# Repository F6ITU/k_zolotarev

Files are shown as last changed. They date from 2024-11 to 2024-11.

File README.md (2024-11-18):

# Zolotarev Low Pass Filter

This lpf filter has been described by Gary Cobb, G3TMG, in QEX (November-December 2016). 

Based on this model, Kjell LA2NI designed a complete low-pass filter, capable of handling (at least) 600W of RF power. 

It's the ideal companion for the Munin400 linear amplifier designed by the same author.

This repository is a strict copy of the original work, using Kicad 8.xx. Original pcb design was made with Ultiboard software

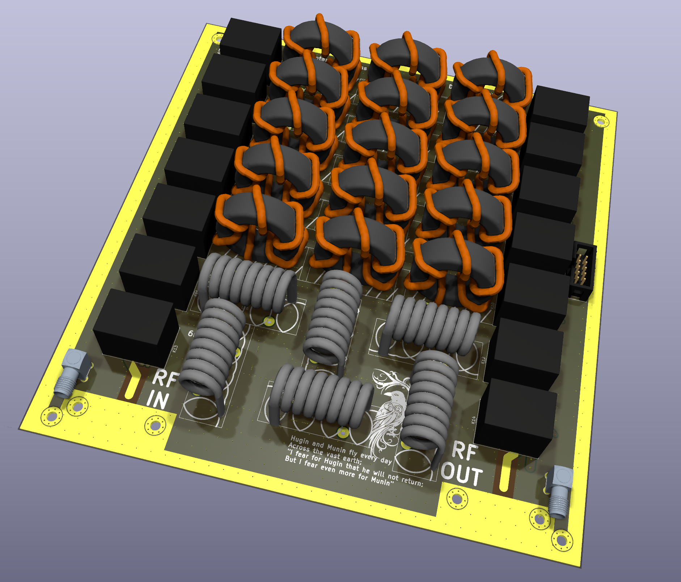
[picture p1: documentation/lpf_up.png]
LPF vu de dessus


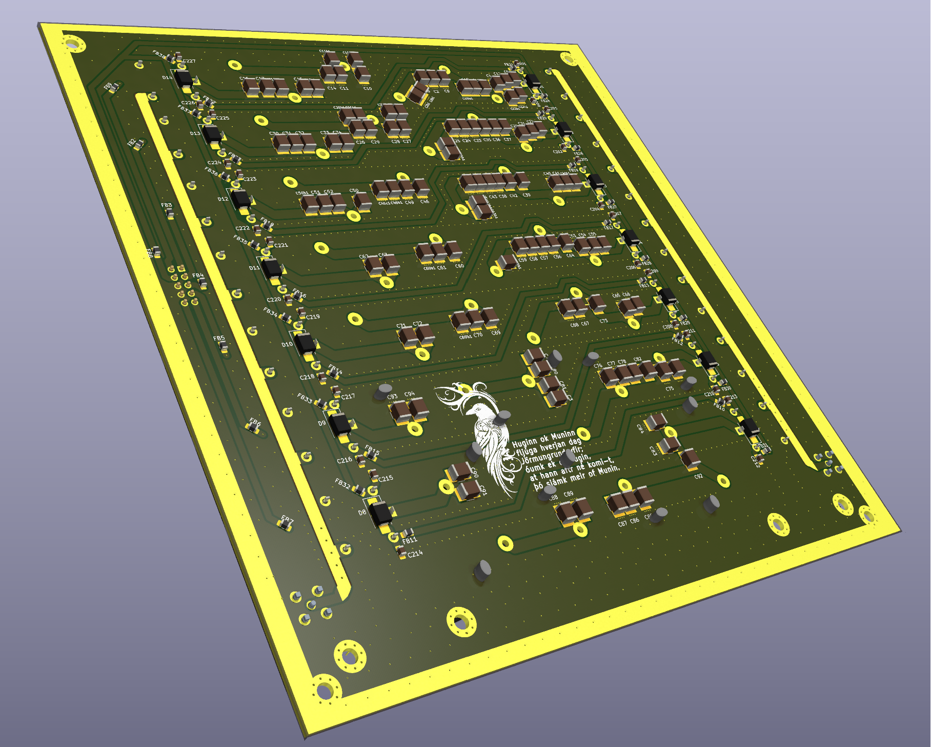
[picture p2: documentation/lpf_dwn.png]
LPF vu de dessous


# Building notes : 

** All capacitors used in the active part of the filter have been sourced as "Vishay Vitramon VJ Hifreq" in 1111 format./**

For   safety reasons and voltage/power handling, the operating voltage of each capacitor should not be less than 1kV.

In other words, since the voltage withstand of MLCC capacitors (or any other technology) decreases as the capacitance increases, the maximum value of each component must not exceed 180 pF (beyond this value, the voltage withstand
resistance collapses at 630 V).

This is why parallel capacitor associations have been provided on the pcb (referenced with the suffix Cxxb1, Cxxb2 etc).

** Two kind of output are available.

- One on SMA connectors

- The other by soldering a coaxial cable directly to the pcb (pigtail input/output)

The second method is preferable, as it's more practical for many hobbyists. However, at these frequencies (1 to 60 MHz), SMA connectors support these power levels perfectly. Avoid connectors made in China.

Input and output wiring on 5mm coax such as RG233 or equivalent (or hand formable SM141 coax cable if SMA are used).

Toroid should be wound with 6 to 8 tenths of a mm wire, air-cores with 8/10 silver-plated wire.

# Work in progress ?

The current state of the filter is considered as "RTM", Beta 1, and considered as "almost definitive" for a first version.

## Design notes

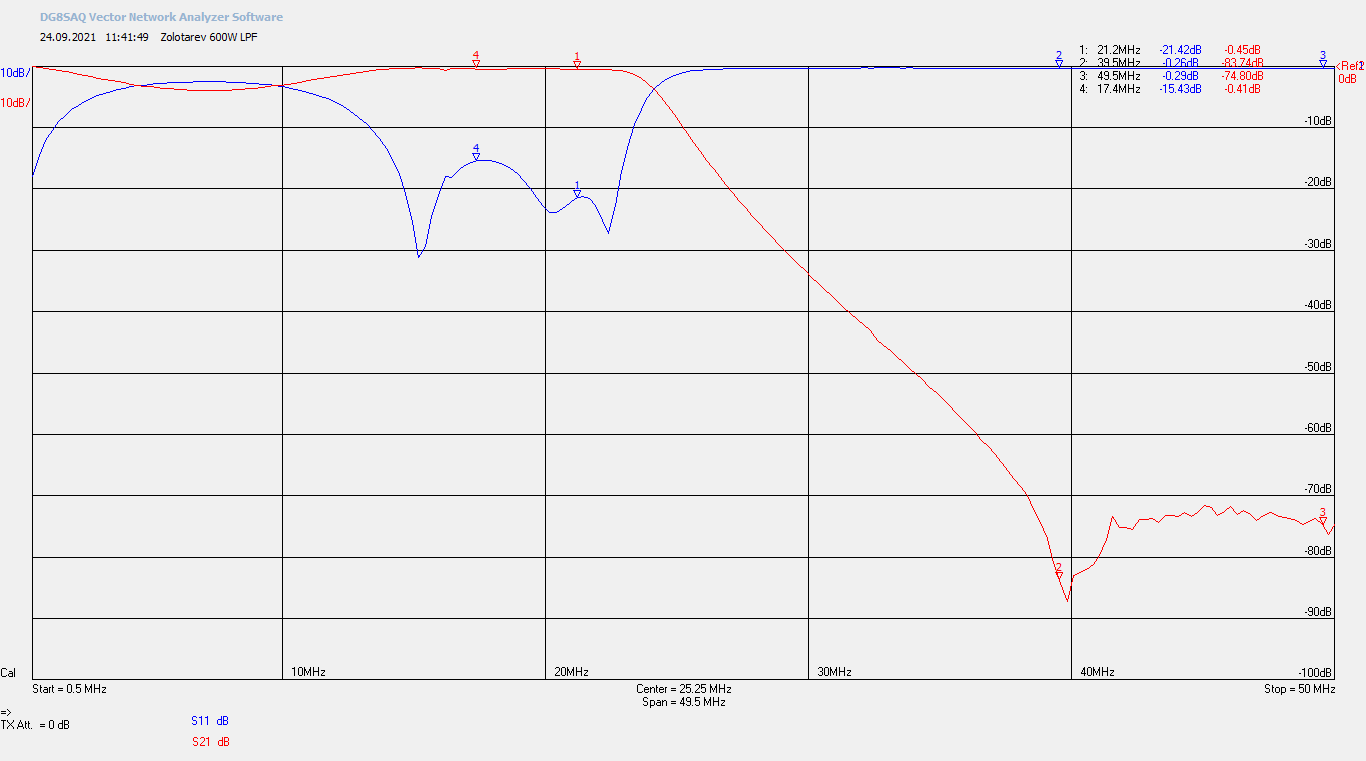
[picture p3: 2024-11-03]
documentation/original LA2NI files/Zolotarev 600W LPF_18+15 metre.png

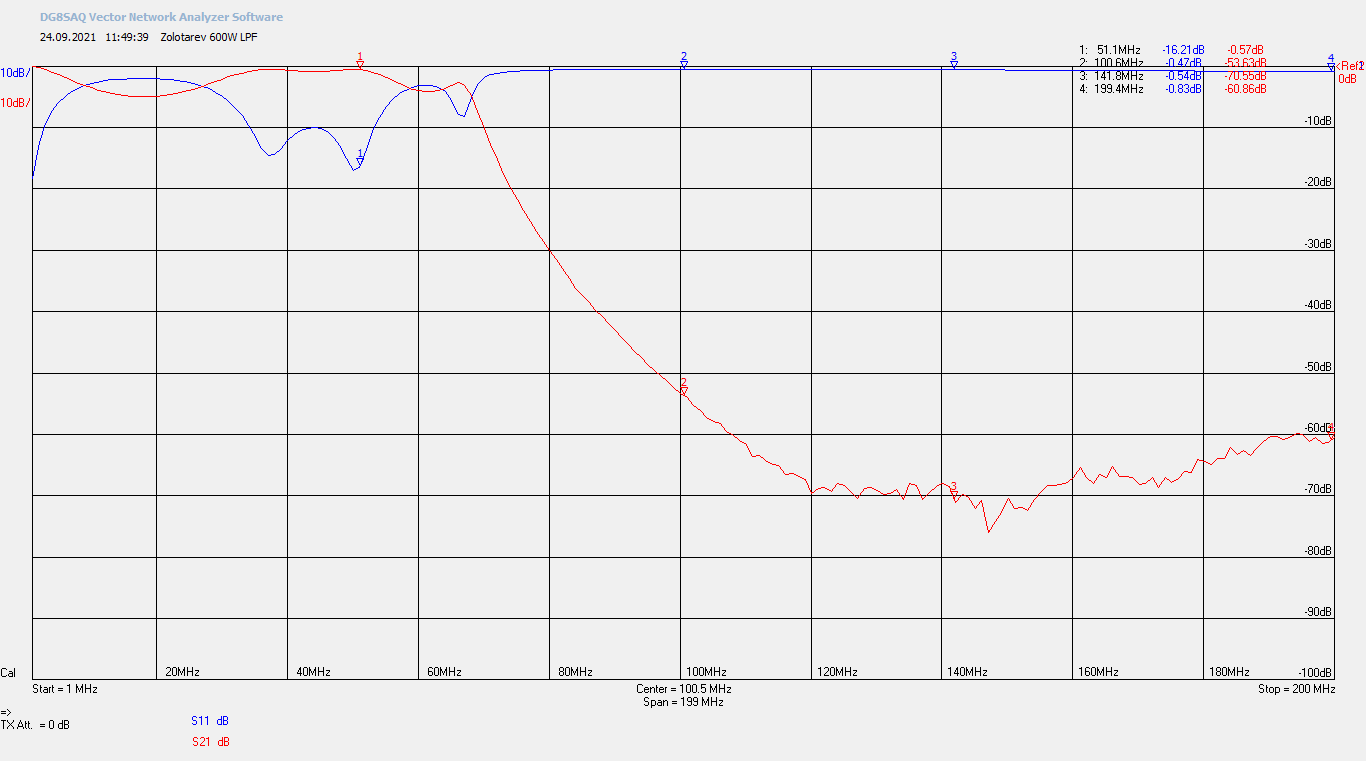
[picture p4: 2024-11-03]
documentation/original LA2NI files/Zolotarev 600W LPF_6 metre.png

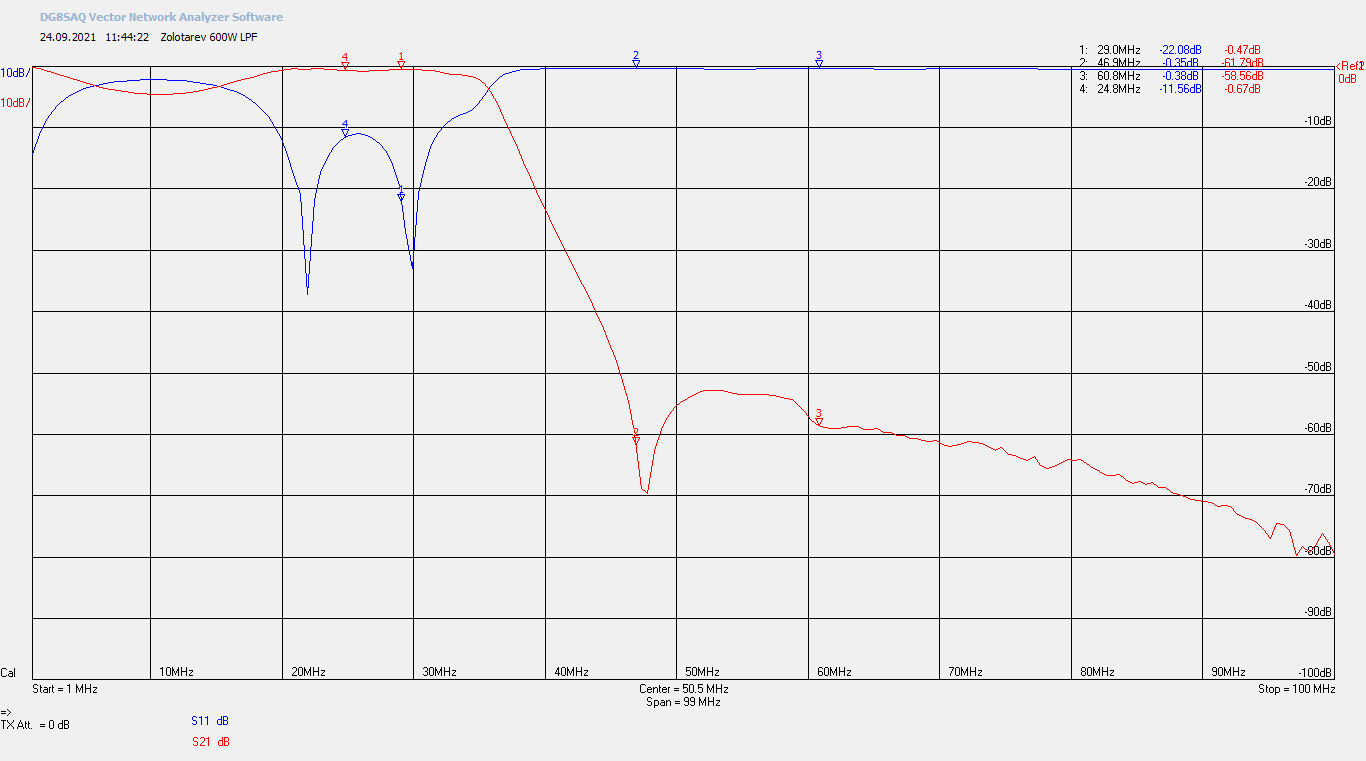
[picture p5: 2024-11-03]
documentation/original LA2NI files/Zolotarev 600W LPF_12+10 metre.png

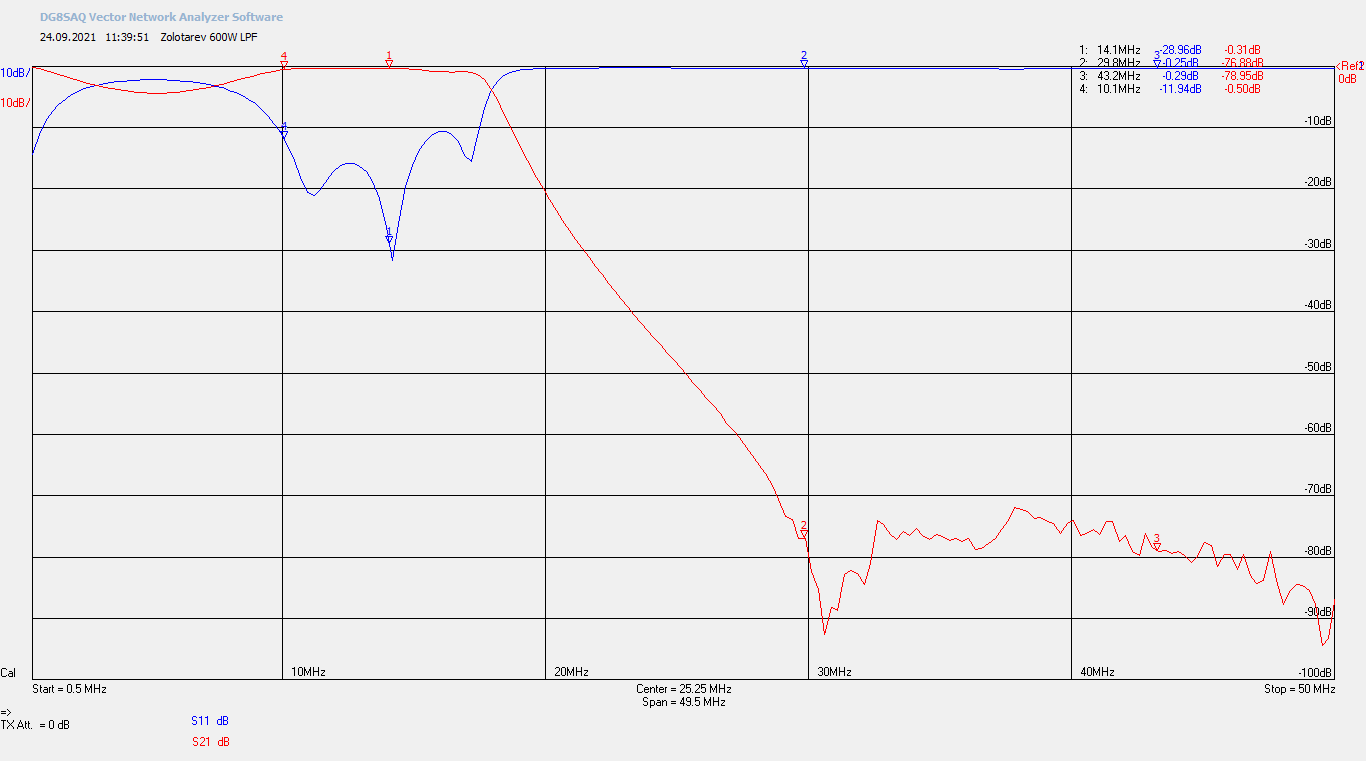
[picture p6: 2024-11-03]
documentation/original LA2NI files/Zolotarev 600W LPF_30+20 metre.png

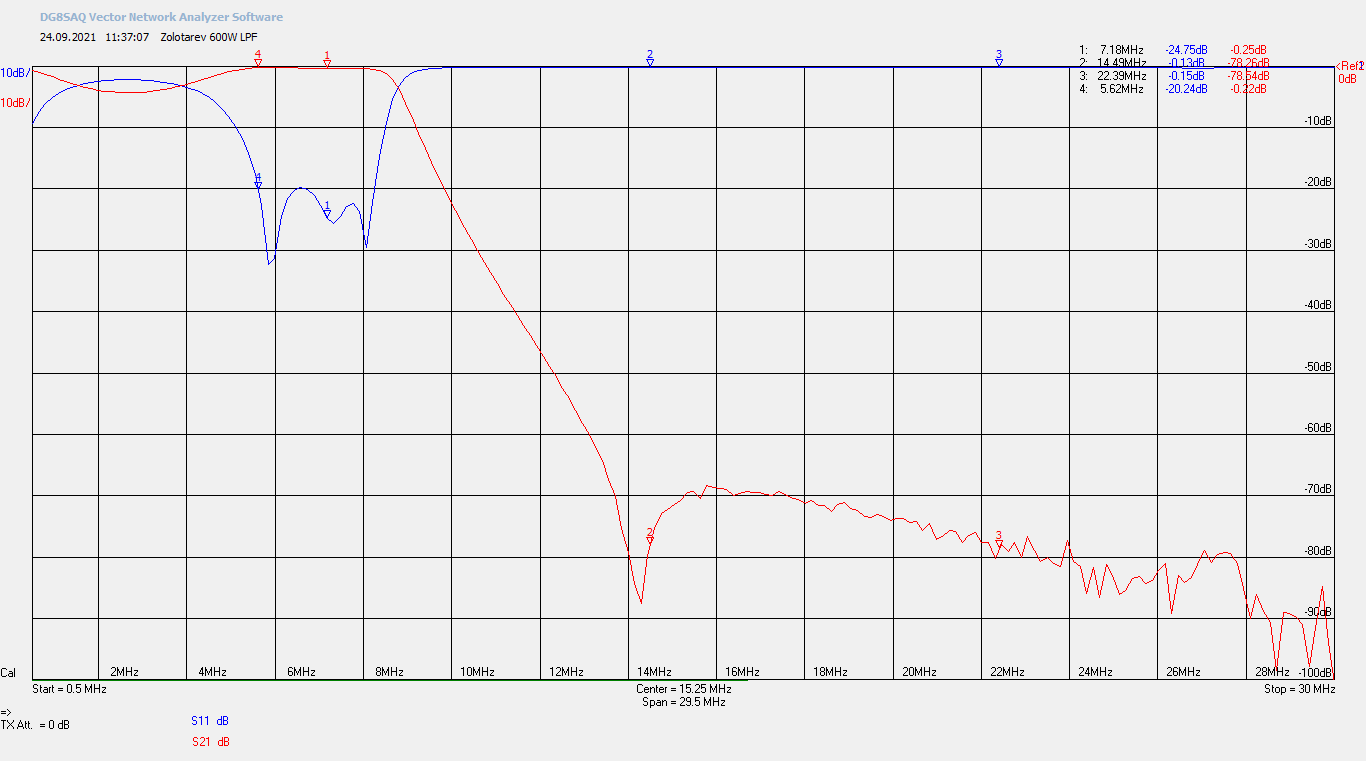
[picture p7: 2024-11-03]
documentation/original LA2NI files/Zolotarev 600W LPF_60+40 metre.png

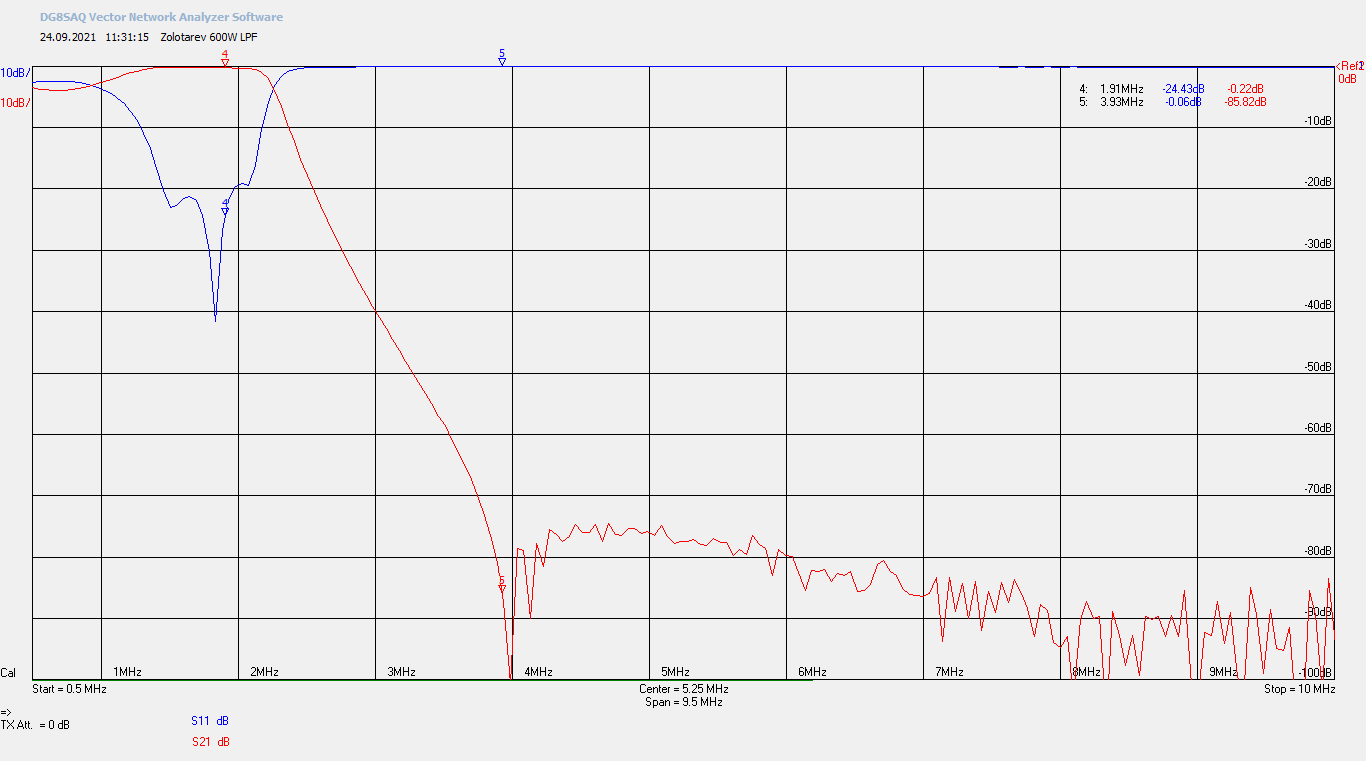
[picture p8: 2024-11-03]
documentation/original LA2NI files/Zolotarev 600W LPF_160 metre.png

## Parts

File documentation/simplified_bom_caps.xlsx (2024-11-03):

valeur | qté | ref mouser | P.U. | total
6
7
10 | X2
11
12 | X2
13
20 | X3
22 | X2
25
29 | X2
30 | X2
33
38
40 | X2
52
68 | X7
100
120
130 | X14
180 | X5
200 | X12
620 | X5
680 | x3
1000 | x7
2200 | x2
2700 | x4
5600
6200

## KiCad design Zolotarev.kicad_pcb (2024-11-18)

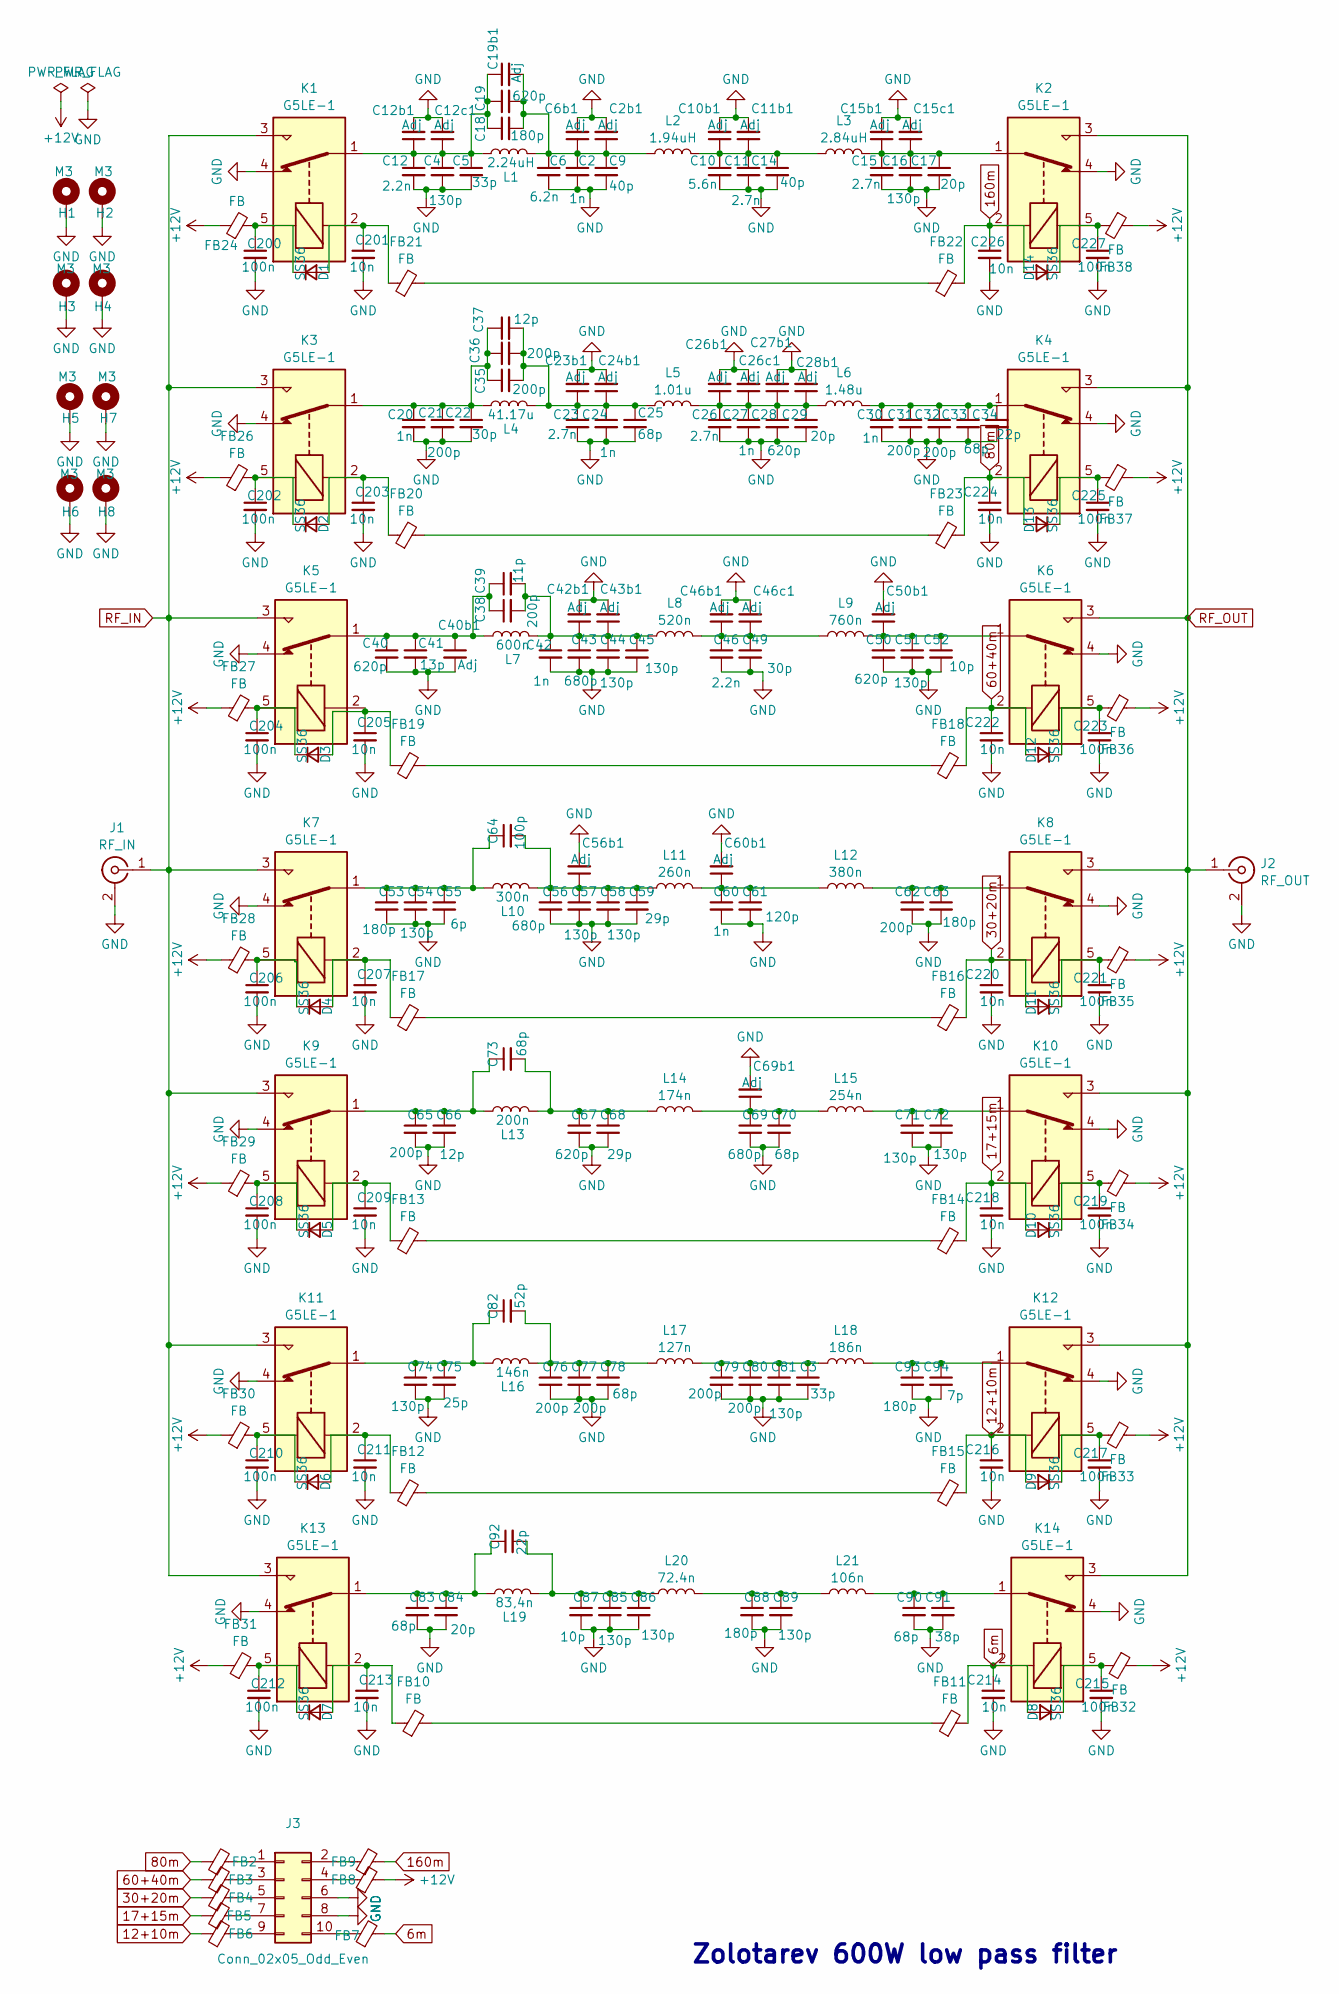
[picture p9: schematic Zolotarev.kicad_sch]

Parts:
C2, C20, C24, C27, C30, C42, C60: 1n; ATC_500_HandSoldering
C2b1, C6b1, C10b1, C11b1, C12b1, C12c1, C15b1, C15c1, C19b1, C23b1, C24b1, C26b1, C26c1, C27b1, C28b1, C40b1, C42b1, C43b1, C46b1, C46c1, C50b1, C56b1, C60b1, C69b1: Adj; ATC_500_HandSoldering
C3, C5: 33p; ATC_500_HandSoldering
C4, C16, C44, C45, C51, C54, C57, C58, C71, C72, C74, C81, C85, C86, C89: 130p; ATC_500_HandSoldering
C6: 6.2n; ATC_500_HandSoldering
C9, C14: 40p; ATC_500_HandSoldering
C10: 5.6n; ATC_500_HandSoldering
C11, C15, C23, C26: 2.7n; ATC_500_HandSoldering
C12, C46: 2.2n; ATC_500_HandSoldering
C17, C29, C84: 20p; ATC_500_HandSoldering
C18, C53, C63, C88, C93: 180p; ATC_500_HandSoldering
C19, C28, C40, C50, C67: 620p; ATC_500_HandSoldering
C21, C31, C32, C35, C36, C38, C62, C65, C76, C77, C79, C80: 200p; ATC_500_HandSoldering
C22, C49: 30p; ATC_500_HandSoldering
C25, C33, C70, C73, C78, C83, C90: 68p; ATC_500_HandSoldering
C34, C92: 22p; ATC_500_HandSoldering
C37, C66: 12p; ATC_500_HandSoldering
C39: 11p; ATC_500_HandSoldering
C41: 13p; ATC_500_HandSoldering
C43, C56, C69: 680p; ATC_500_HandSoldering
C52, C87: 10p; ATC_500_HandSoldering
C55: 6p; ATC_500_HandSoldering
C59, C68: 29p; ATC_500_HandSoldering
C61: 120p; ATC_500_HandSoldering
C64: 100p; ATC_500_HandSoldering
C75: 25p; ATC_500_HandSoldering
C82: 52p; ATC_500_HandSoldering
C91: 38p; ATC_500_HandSoldering
C94: 7p; ATC_500_HandSoldering
C200, C202, C204, C206, C208, C210, C212, C215, C217, C219, C221, C223, C225, C227: 100n; C_0805_2012Metric_Pad1.18x1.45mm_HandSolder
C201, C203, C205, C207, C209, C211, C213, C214, C216, C218, C220, C222, C224, C226: 10n; C_0805_2012Metric_Pad1.18x1.45mm_HandSolder
D1, D2, D3, D4, D5, D6, D7, D8, D9, D10, D11, D12, D13, D14: SS36; D_SMB_Handsoldering
FB2, FB3, FB4, FB5, FB6, FB7, FB8, FB9, FB10, FB11, FB12, FB13, FB14, FB15, FB16, FB17, FB18, FB19, FB20, FB21, FB22, FB23, FB24, FB26, FB27, FB28, FB29, FB30, FB31, FB32, FB33, FB34, FB35, FB36, FB37, FB38: FB; L_0805_2012Metric_Pad1.15x1.40mm_HandSolder
H1, H2, H3, H4, H5, H6, H7, H8: M3; MountingHole_3.5mm_Pad_Via
J1: RF_IN; SMA_PINS
J2: RF_OUT; SMA_PINS
J3: Conn_02x05_Odd_Even; IDC-Header_2x05_P2.54mm_Vertical
K1, K2, K3, K4, K5, K6, K7, K8, K9, K10, K11, K12, K13, K14: G5LE-1; Relay_SPDT_Omron-G5LE-1
L1: 2.24uH; T90_60_V
L2: 1.94uH; T90_60_V
L3: 2.84uH; T90_60_V
L4: 41.17u; T90_60_V
L5: 1.01u; T90_60_V
L6: 1.48u; T90_60_V
L7: 600n; T90_60_V
L8: 520n; T90_60_V
L9: 760n; T90_60_V
L10: 300n; T90_60_V
L11: 260n; T90_60_V
L12: 380n; T90_60_V
L13: 200n; T90_60_V
L14: 174n; T90_60_V
L15: 254n; T90_60_V
L16: 146n; Large_Air_Coil
L17: 127n; Large_Air_Coil
L18: 186n; Large_Air_Coil
L19: 83,4n; Large_Air_Coil
L20: 72.4n; Large_Air_Coil
L21: 106n; Large_Air_Coil

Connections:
6m: C214.1, D8.2 (A), FB7.2, FB11.2, K14.2
12+10m: C216.1, D9.2 (A), FB6.1, FB15.2, K12.2
17+15m: C218.1, D10.2 (A), FB5.1, FB14.2, K10.2
30+20m: C220.1, D11.2 (A), FB4.1, FB16.2, K8.2
60+40m: C222.1, D12.2 (A), FB3.1, FB18.2, K6.2
80m: C224.1, D13.2 (A), FB2.1, FB23.2, K4.2
160m: C226.1, D14.2 (A), FB9.2, FB22.2, K2.2
+12V: FB8.2, FB24.1, FB26.1, FB27.1, FB28.1, FB29.1, FB30.1, FB31.1, FB32.1, FB33.1, FB34.1, FB35.1, FB36.1, FB37.1, FB38.1
GND: C2.2, C2b1.2, C3.2, C4.2, C5.2, C6.2, C6b1.2, C9.2, C10.2, C10b1.2, C11.2, C11b1.2, C12.2, C12b1.2, C12c1.2, C14.2, C15.2, C15b1.2, C15c1.2, C16.2, C17.2, C20.2, C21.2, C22.2, C23.2, C23b1.2, C24.2, C24b1.2, C25.2, C26.2, C26b1.2, C26c1.2, C27.2, C27b1.2, C28.2, C28b1.2, C29.2, C30.2, C31.2, C32.2, C33.2, C34.2, C40.2, C40b1.2, C41.2, C42.2, C42b1.2, C43.2, C43b1.2, C44.2, C45.2, C46.2, C46b1.2, C46c1.2, C49.2, C50.2, C50b1.2, C51.2, C52.2, C53.2, C54.2, C55.2, C56.2, C56b1.2, C57.2, C58.2, C59.2, C60.2, C60b1.2, C61.2, C62.2, C63.2, C65.2, C66.2, C67.2, C68.2, C69.2, C69b1.2, C70.2, C71.2, C72.2, C74.2, C75.2, C76.2, C77.2, C78.2, C79.2, C80.2, C81.2, C83.2, C84.2, C85.2, C86.2, C87.2, C88.2, C89.2, C90.2, C91.2, C93.2, C94.2, C200.2, C201.2, C202.2, C203.2, C204.2, C205.2, C206.2, C207.2, C208.2, C209.2, C210.2, C211.2, C212.2, C213.2, C214.2, C215.2, C216.2, C217.2, C218.2, C219.2, C220.2, C221.2, C222.2, C223.2, C224.2, C225.2, C226.2, C227.2, H1.1, H2.1, H3.1, H4.1, H5.1, H6.1, H7.1, H8.1, J1.2 (Ext), J2.2 (Ext), J3.6, J3.8, K1.4, K2.4, K3.4, K4.4, K5.4, K6.4, K7.4, K8.4, K9.4, K10.4, K11.4, K12.4, K13.4, K14.4
unnamed: C3.1, C79.1, C80.1, C81.1, L17.2, L18.2
unnamed: C10.1, C10b1.1, C11.1, C11b1.1, C14.1, L2.2, L3.2
unnamed: C4.1, C5.1, C12.1, C12b1.1, C12c1.1, C18.1, C19.1, C19b1.1, K1.1, L1.1
unnamed: C15.1, C15b1.1, C15c1.1, C16.1, C17.1, K2.1, L3.1
unnamed: C2.1, C2b1.1, C6.1, C6b1.1, C9.1, C18.2, C19.2, C19b1.2, L1.2, L2.1
unnamed: C20.1, C21.1, C22.1, C35.1, C36.1, C37.1, K3.1, L4.1
unnamed: C23.1, C23b1.1, C24.1, C24b1.1, C25.1, C35.2, C36.2, C37.2, L4.2, L5.1
unnamed: C26.1, C26b1.1, C26c1.1, C27.1, C27b1.1, C28.1, C28b1.1, C29.1, L5.2, L6.2
unnamed: C30.1, C31.1, C32.1, C33.1, C34.1, K4.1, L6.1
unnamed: C38.1, C39.1, C40.1, C40b1.1, C41.1, K5.1, L7.1
unnamed: C38.2, C39.2, C42.1, C42b1.1, C43.1, C43b1.1, C44.1, C45.1, L7.2, L8.1
unnamed: C46.1, C46b1.1, C46c1.1, C49.1, L8.2, L9.2
unnamed: C50.1, C50b1.1, C51.1, C52.1, K6.1, L9.1
unnamed: C53.1, C54.1, C55.1, C64.1, K7.1, L10.1
unnamed: C56.1, C56b1.1, C57.1, C58.1, C59.1, C64.2, L10.2, L11.1
unnamed: C60.1, C60b1.1, C61.1, L11.2, L12.2
unnamed: C62.1, C63.1, K8.1, L12.1
unnamed: C65.1, C66.1, C73.1, K9.1, L13.1
unnamed: C67.1, C68.1, C73.2, L13.2, L14.1
unnamed: C69.1, C69b1.1, C70.1, L14.2, L15.2
unnamed: C71.1, C72.1, K10.1, L15.1
unnamed: C74.1, C75.1, C82.1, K11.1, L16.1
unnamed: C76.1, C77.1, C78.1, C82.2, L16.2, L17.1
unnamed: C83.1, C84.1, C92.1, K13.1, L19.1
unnamed: C85.1, C86.1, C87.1, C92.2, L19.2, L20.1
unnamed: C88.1, C89.1, L20.2, L21.2
unnamed: C90.1, C91.1, K14.1, L21.1
unnamed: C93.1, C94.1, K12.1, L18.1
unnamed: C201.1, D1.2 (A), FB21.1, K1.2
unnamed: C200.1, D1.1 (K), FB24.2, K1.5
unnamed: C203.1, D2.2 (A), FB20.1, K3.2
unnamed: C202.1, D2.1 (K), FB26.2, K3.5
unnamed: C205.1, D3.2 (A), FB19.1, K5.2
unnamed: C204.1, D3.1 (K), FB27.2, K5.5
unnamed: C207.1, D4.2 (A), FB17.1, K7.2
unnamed: C206.1, D4.1 (K), FB28.2, K7.5
unnamed: C209.1, D5.2 (A), FB13.1, K9.2
unnamed: C208.1, D5.1 (K), FB29.2, K9.5
unnamed: C211.1, D6.2 (A), FB12.1, K11.2
unnamed: C210.1, D6.1 (K), FB30.2, K11.5
unnamed: C213.1, D7.2 (A), FB10.1, K13.2
unnamed: C212.1, D7.1 (K), FB31.2, K13.5
unnamed: C215.1, D8.1 (K), FB32.2, K14.5
unnamed: C217.1, D9.1 (K), FB33.2, K12.5
unnamed: C219.1, D10.1 (K), FB34.2, K10.5
unnamed: C221.1, D11.1 (K), FB35.2, K8.5
unnamed: C223.1, D12.1 (K), FB36.2, K6.5
unnamed: C225.1, D13.1 (K), FB37.2, K4.5
unnamed: C227.1, D14.1 (K), FB38.2, K2.5
unnamed: FB10.2, FB11.1
unnamed: FB12.2, FB15.1
unnamed: FB13.2, FB14.1
unnamed: FB16.1, FB17.2
unnamed: FB18.1, FB19.2
unnamed: FB20.2, FB23.1
unnamed: FB21.2, FB22.1
unnamed: FB2.2, J3.1
unnamed: FB9.1, J3.2
unnamed: FB3.2, J3.3
unnamed: FB8.1, J3.4
unnamed: FB4.2, J3.5
unnamed: FB5.2, J3.7
unnamed: FB6.2, J3.9
unnamed: FB7.1, J3.10
RF_IN: J1.1 (In), K1.3, K3.3, K5.3, K7.3, K9.3, K11.3, K13.3
RF_OUT: J2.1 (In), K2.3, K4.3, K6.3, K8.3, K10.3, K12.3, K14.3

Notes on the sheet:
Zolotarev 600W low pass filter

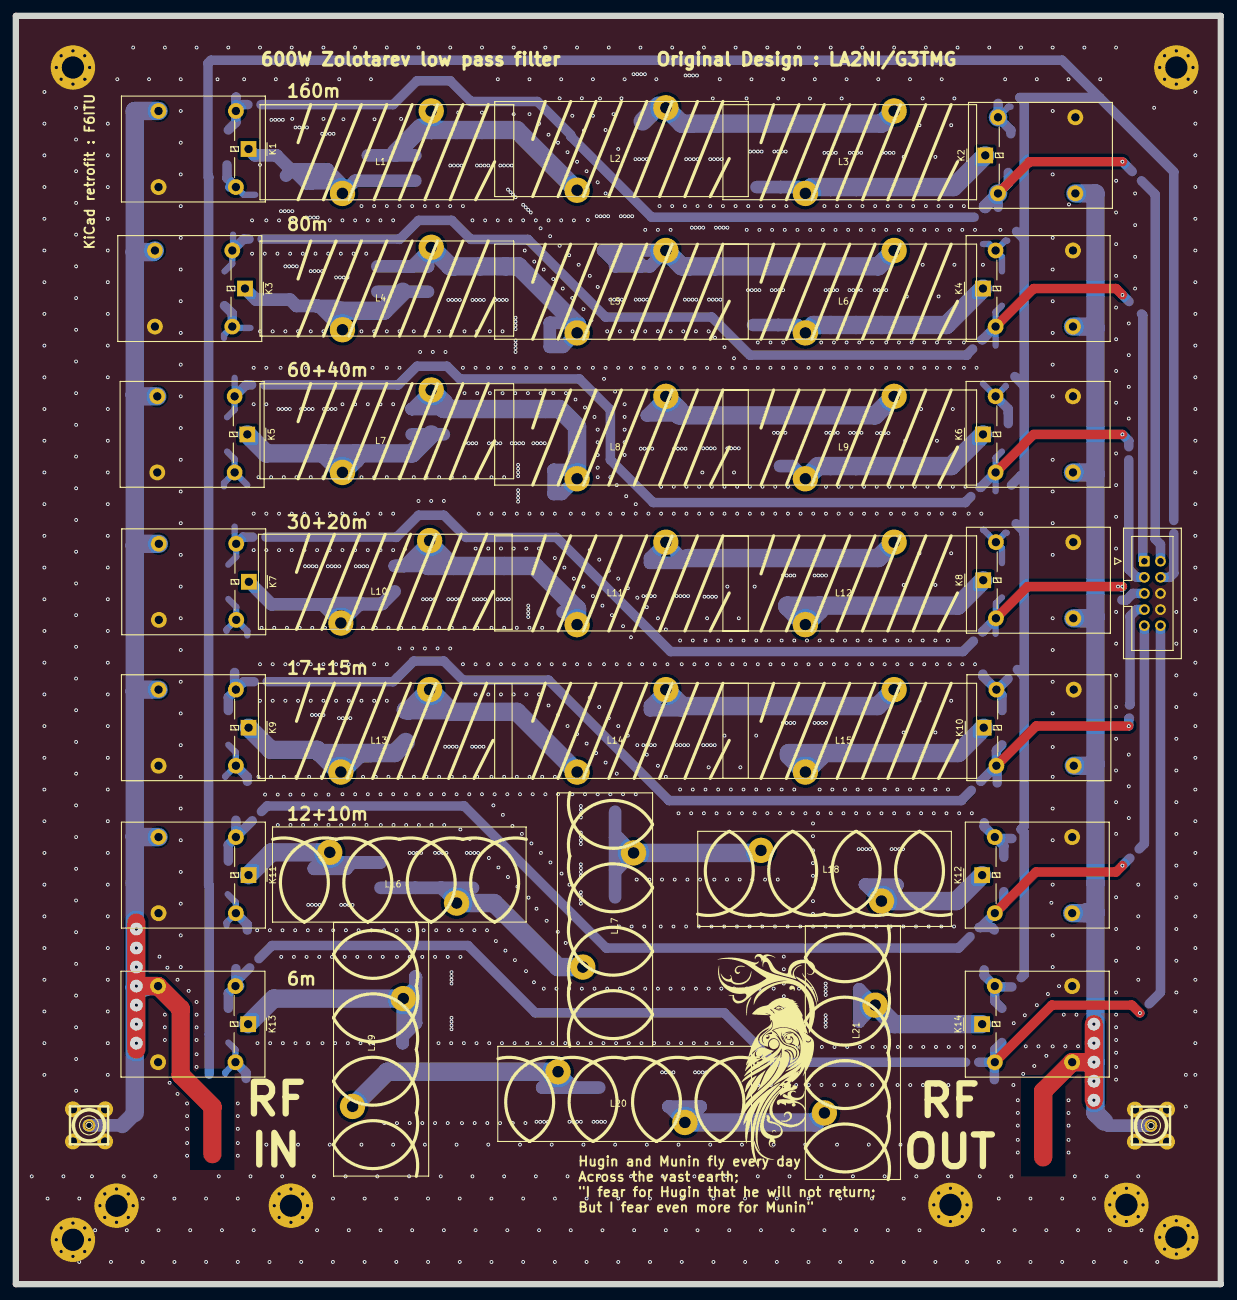
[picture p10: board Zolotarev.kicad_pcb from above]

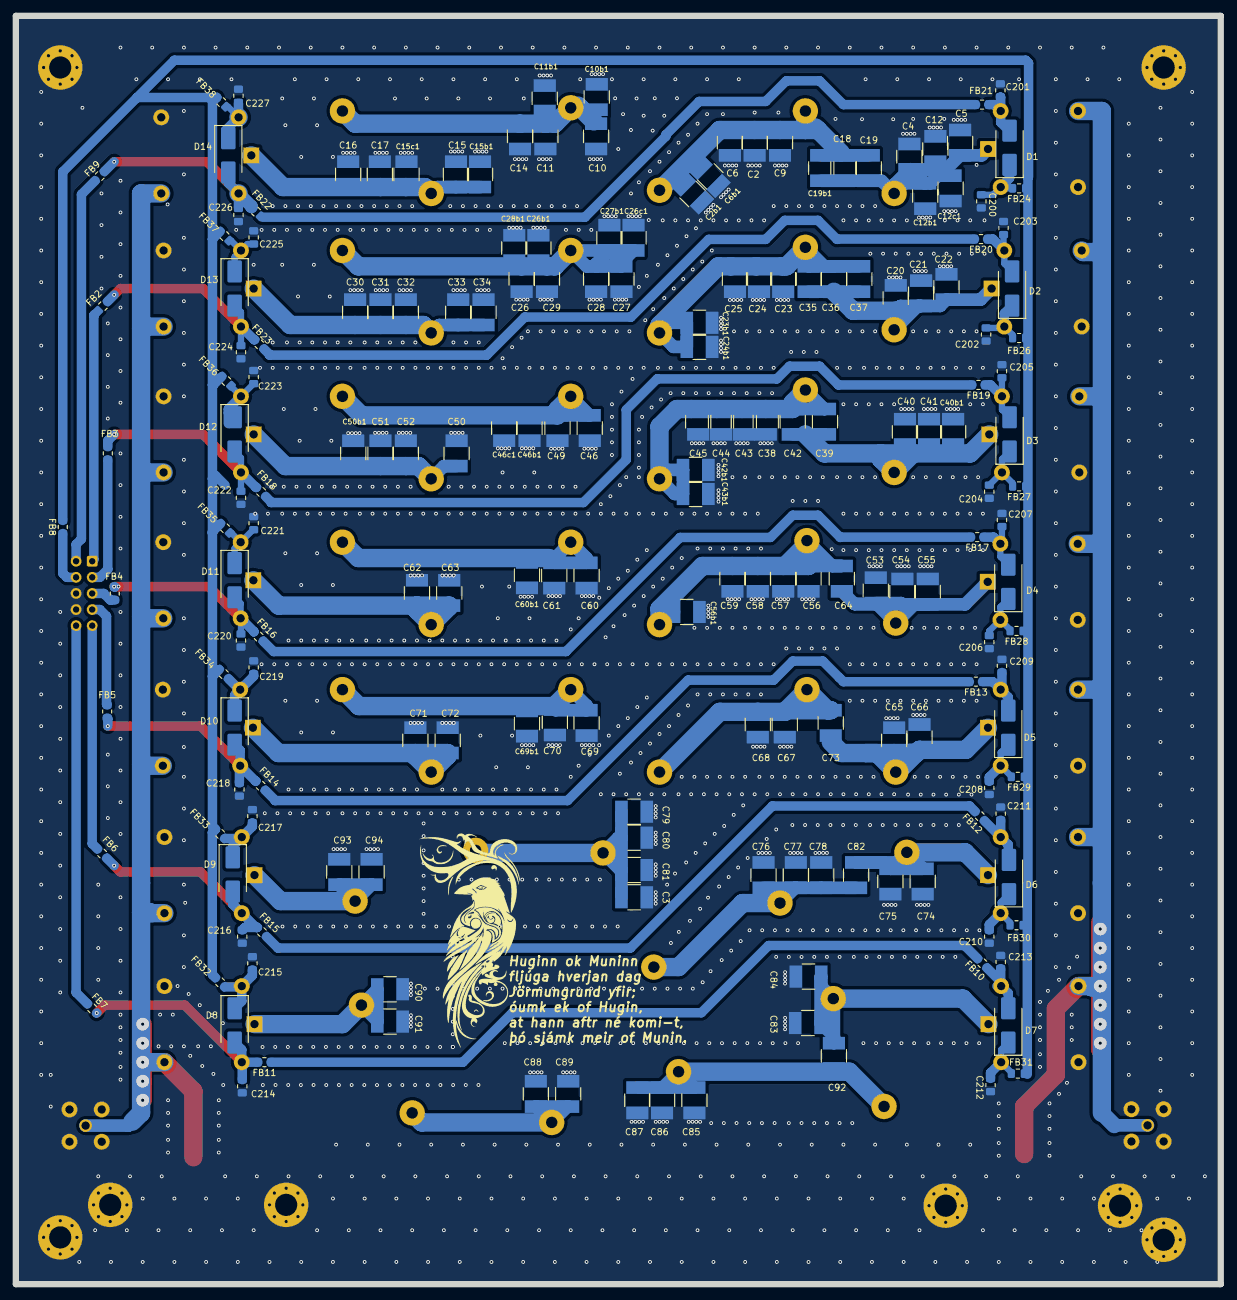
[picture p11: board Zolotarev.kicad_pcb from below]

Board: 2 copper layers, 190.0 x 200.0 mm, 236 parts (190 on the bottom side), 75 nets.

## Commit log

2024-11-03 initial project, schematic under dev
    [Zolotarev.kicad_pcb, Zolotarev.kicad_sch, bom caps 600.xlsx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]
2024-11-04 schematic completed, devices def TBD
    [Zolotarev.kicad_sch]
2024-11-06 beginning to assign 3D forms
    [Zolotarev.kicad_pcb, Zolotarev.kicad_sch]
2024-11-07 minor corrections, first band routed
    [Zolotarev.kicad_pcb, Zolotarev.kicad_sch]
2024-11-08 3 bands over 7
    [Zolotarev.kicad_pcb, Zolotarev.kicad_sch]
2024-11-08 5 bands routed, 2 more to come
    [Zolotarev.kicad_pcb, Zolotarev.kicad_sch]
2024-11-09 all bands routed, command connector to do
    [Zolotarev.kicad_sch]
2024-11-09 silkmask partly added
    [Zolotarev.kicad_pcb, Zolotarev.kicad_sch]
2024-11-10 diodes changed for smb, silk cleaned
    [Zolotarev.kicad_pcb, Zolotarev.kicad_sch]
2024-11-11 control connector and some ferrites later
    [Zolotarev.kicad_pcb, Zolotarev.kicad_sch]
2024-11-18 routing, silk, zone cleanup and Gerber completed, RTM release
    [Zolotarev-B_Cu.gbl, Zolotarev-B_Mask.gbs, Zolotarev-B_Paste.gbp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]
